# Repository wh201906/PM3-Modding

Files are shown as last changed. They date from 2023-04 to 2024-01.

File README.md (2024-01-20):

# PM3 Modding

## PM3_Flash
Add the external SPI flash to the PM3 Easy  
[README](/PM3_Flash/README.md)  
[Schematic](./PM3_Flash/hardware/PM3_Flash-schematic.pdf)  
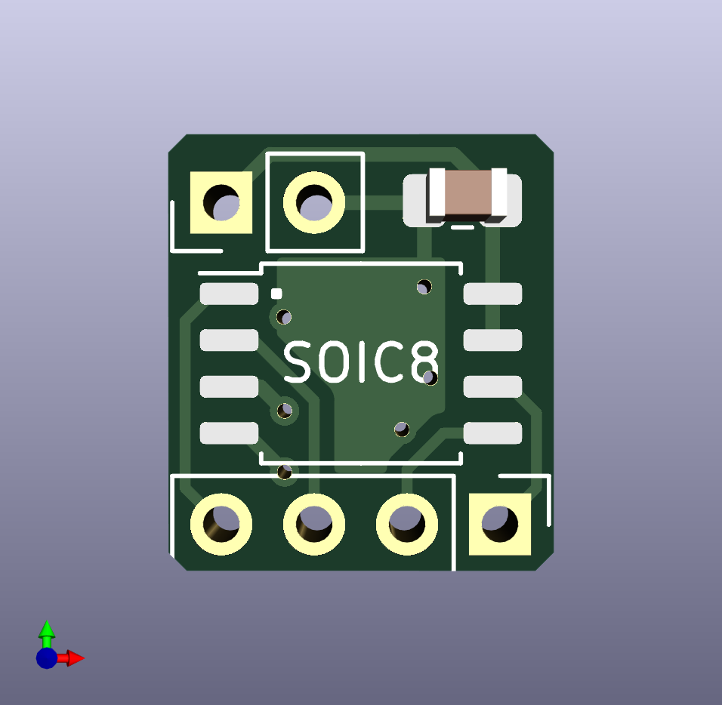
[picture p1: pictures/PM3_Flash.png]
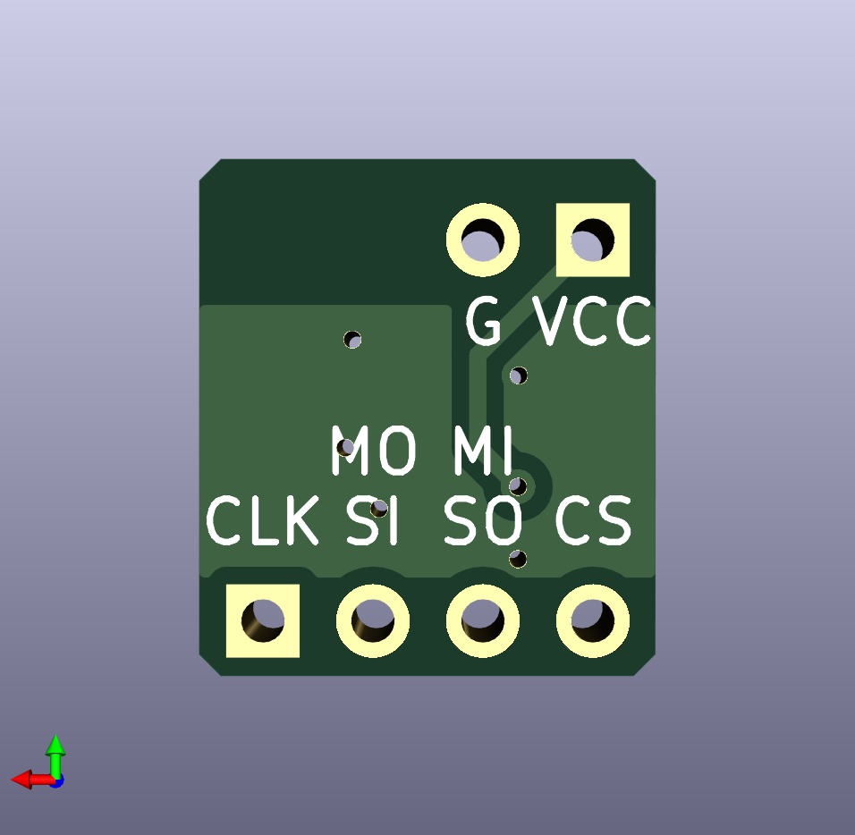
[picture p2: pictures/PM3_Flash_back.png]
    

## PM3_ISO7816
Add the smartcard module to the PM3 Easy  
[README](/PM3_ISO7816/README.md)  
[Schematic](./PM3_ISO7816/hardware/PM3_ISO7816-schematic.pdf)  
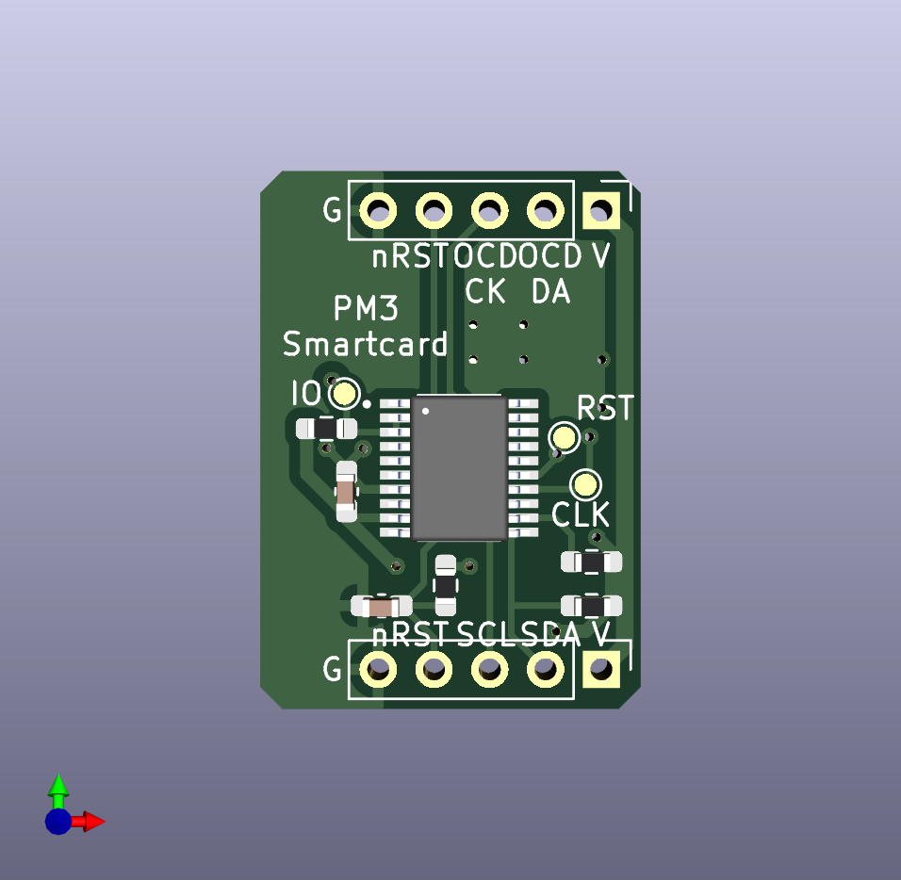
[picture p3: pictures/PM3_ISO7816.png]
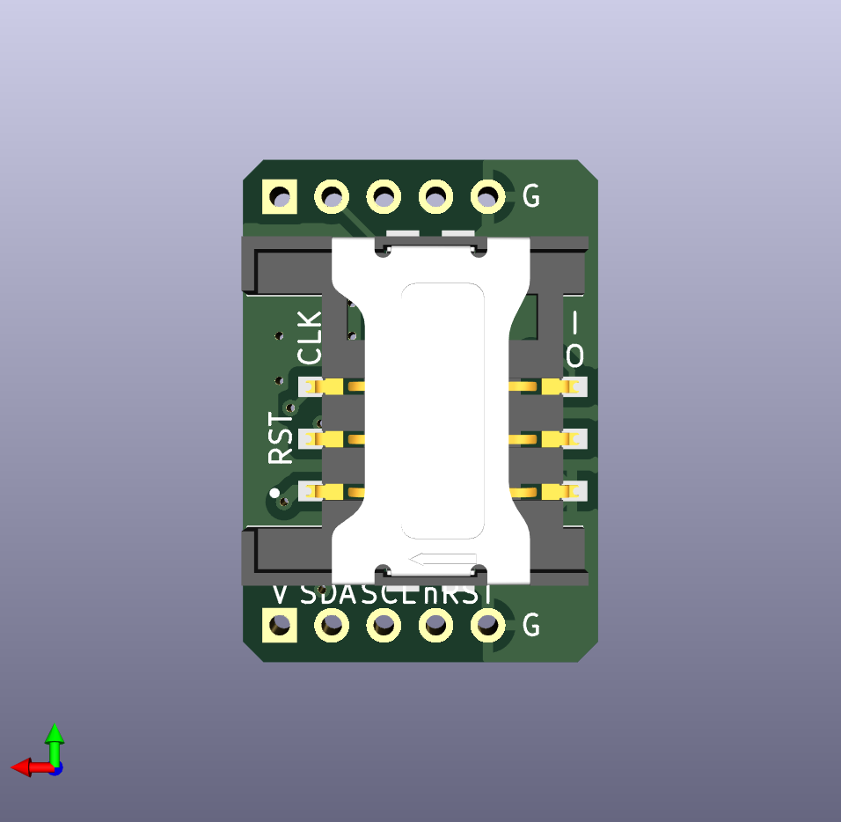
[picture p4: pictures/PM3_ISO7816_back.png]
    

## PM3_USB2TCP
[README](/PM3_USB2TCP/README.md)  
Connect to PM3 hardware with TCP, using ESP32-S3/S2 as a USB to TCP bridge  
No need to jumping any wires to the MCU directly. It works with most of the ESP32-S3/S2 dev boards  

## PM3_USB2UDP
[README](/PM3_USB2UDP/README.md)  
Connect to PM3 hardware with UDP, like `PM3_USB2TCP` but faster  

## License
All hardware projects in this repository are licensed under [CERN Open Hardware Licence Version 2 - Weakly Reciprocal](LICENSE.CERN-OHL-W).  
All software(firmware) projects in this repository are licensed under [GNU General Public License v3.0](LICENSE.GPL).

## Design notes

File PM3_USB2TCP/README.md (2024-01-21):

# PM3 USB to TCP Bridge

Connect to PM3 hardware with TCP, using ESP32-S3/S2 as a USB to TCP bridge.  
This modding only contains the firmware of ESP32-S3, and it should work on most of the ESP32-S3 and ESP32-S2 dev boards.  

# Tips:
1. To use this modding, you need a Proxmark3 client newer than commit [9c947eddcdbc66e76be6b33be9af4ce75e730b92](https://github.com/RfidResearchGroup/proxmark3/commit/9c947eddcdbc66e76be6b33be9af4ce75e730b92)
2. You need ESP-IDF or GitHub Action to build this project
3. The ESP32-S3 can work as a soft-AP. The SSID and the password are defined in [PM3_Modding/PM3_USB2TCP/firmware/main/wifi/wifi.h](./firmware/main/wifi/wifi.h)
4. To connect to an existing AP like wireless router or mobile hotspot, you should follow these steps:  
    + Set the correct SSID and password in [PM3_Modding/PM3_USB2TCP/firmware/main/wifi/wifi.h](./firmware/main/wifi/wifi.h)
    + Comment out `wifi_init_softap();` in [PM3_Modding/PM3_USB2TCP/firmware/main/app_main.c](./firmware/main/app_main.c)
    + Uncomment `wifi_init_sta();` in [PM3_Modding/PM3_USB2TCP/firmware/main/app_main.c](./firmware/main/app_main.c)
    + To get the IP address allocated by the DHCP server, you can check the output on UART0(GPIO43 for Tx, GPIO44 for Rx) or the management page of the router
    + (Optional) If it's not convenient to get the allocated IP address, you can set the static IP address in [PM3_Modding/PM3_USB2TCP/firmware/main/wifi/wifi.h](./firmware/main/wifi/wifi.h)
5. The default IP address of ESP32-S3 is `192.168.4.1`(soft-AP mode). The server port is defined in [PM3_Modding/PM3_USB2TCP/firmware/main/tcp-server.h](./firmware/main/tcp-server.h)
6. ESP32-S2 also has the USB-Host peripheral, so it also works. Remember to set the correct target chip in ESP-IDF.
7. Some of the arguments mentioned above can be configured by running `idf.py menuconfig` -> `USB Bridge Configuration`.

# Hardware Connection

| ESP32-S3 | PM3 |
| --- | --- |
| GND | GND |
| GPIO19 | USB_D- |
| GPIO20 | USB_D+ |
| 5V | 5V |

The 5V pin is optional.

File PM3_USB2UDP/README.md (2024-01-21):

# PM3 USB to UDP Bridge

Connect to PM3 hardware with UDP, using ESP32-S3/S2 as a USB to UDP bridge.  
This modding only contains the firmware of ESP32-S3, and it should work on most of the ESP32-S3 and ESP32-S2 dev boards.  

# Tips:
1. To use this modding, you need a Proxmark3 client newer than commit [0c0967bcc56773e0b014fd4d89d5f893052928d3](https://github.com/RfidResearchGroup/proxmark3/commit/0c0967bcc56773e0b014fd4d89d5f893052928d3)
2. You need ESP-IDF or GitHub Action to build this project
3. The ESP32-S3 can work as a soft-AP. The SSID and the password are defined in [PM3_Modding/PM3_USB2UDP/firmware/main/wifi/wifi.h](./firmware/main/wifi/wifi.h)
4. To connect to an existing AP like wireless router or mobile hotspot, you should follow these steps:  
    + Set the correct SSID and password in [PM3_Modding/PM3_USB2UDP/firmware/main/wifi/wifi.h](./firmware/main/wifi/wifi.h)
    + Comment out `wifi_init_softap();` in [PM3_Modding/PM3_USB2UDP/firmware/main/app_main.c](./firmware/main/app_main.c)
    + Uncomment `wifi_init_sta();` in [PM3_Modding/PM3_USB2UDP/firmware/main/app_main.c](./firmware/main/app_main.c)
    + To get the IP address allocated by the DHCP server, you can check the output on UART0(GPIO43 for Tx, GPIO44 for Rx) or the management page of the router
    + (Optional) If it's not convenient to get the allocated IP address, you can set the static IP address in [PM3_Modding/PM3_USB2UDP/firmware/main/wifi/wifi.h](./firmware/main/wifi/wifi.h)
5. The default IP address of ESP32-S3 is `192.168.4.1`(soft-AP mode). The server port is defined in [PM3_Modding/PM3_USB2UDP/firmware/main/tcp-server.h](./firmware/main/udp-server.h)
6. ESP32-S2 also has the USB-Host peripheral, so it also works. Remember to set the correct target chip in ESP-IDF.
7. Some of the arguments mentioned above can be configured by running `idf.py menuconfig` -> `USB Bridge Configuration`.

# Hardware Connection

| ESP32-S3 | PM3 |
| --- | --- |
| GND | GND |
| GPIO19 | USB_D- |
| GPIO20 | USB_D+ |
| 5V | 5V |

The 5V pin is optional.

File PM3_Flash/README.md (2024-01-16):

# PM3 Flash

Add the external SPI flash to the Proxmark3 Easy, to unlock all of the standalone modes.  

# Tips:
1. Some of the new Proxmark3 Easy has already intergrated an external SPI flash. If you know how to flash the firmware to the Proxmark3 Easy, you can try to flash a SPI flash enabled firmware to test if the external flash exists.
2. The SPI flash chip will be powered at 3.3V, but some SPI flash chips on the market can only be powered at 1.xV.
3. The SPI flash on the Proxmark3 RDV4 has a capacity of 256kBytes, but you can also use chips with higher capacity. Only 256kBytes will be used unless you changed the code of the firmware.
4. To use the SPI flash, you need to flash your Proxmark3 with SPI flash enabled firmware.
5. To initialize the SPI flash, you need to run the [Proxmark3/client/luascripts/init_rdv4.lua](https://github.com/RfidResearchGroup/proxmark3/blob/v4.16717/client/luascripts/init_rdv4.lua) in the client.

# Soldering

| Module | MCU  |
| --- | ---- |
| VCC | 3.3V |
| GND | GND  |
| CLK | PA14 |
| MISO | PA12 |
| MOSI | PA13 |
| CS | PA10 |

Please refer to the datasheet of AT91SAM7Sxxx to find the physical position of these pins.  
For some of the old Proxmark3 Easy, the PA14_SPCK, PA12_MISO and PA13_MOSI pin are exported near the JTAG pins. You only need to jump 1 wire(PA10_NPCS2) to the MCU directly.

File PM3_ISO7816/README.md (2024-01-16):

# PM3 ISO7816

Add the smartcard module to the Proxmark3 Easy.  

# Tips:
1. The MCU on the original smartcard module is Nuvoton's N76E003xQ20. I use the TSSOP-20 package(N76E003AT20) rather than QFN-20 package for easier manufacturing. The firmware works on both of them.
2. The firmware is separated into LDROM(kinda like bootloader) and APROM. To use this module, you need to flash the LDROM and APROM to the MCU first. 
3. The APROM can be found in the [Proxmark3 RRG repo](https://github.com/RfidResearchGroup/proxmark3/blob/v4.16717/client/resources/sim013.bin) with its [source code](https://github.com/RfidResearchGroup/proxmark3/blob/v4.16717/tools/simmodule/sim013.asm). The LDROM is [PM3_Modding/PM3_ISO7816/firmware/LDROM.bin](./firmware/LDROM.bin), which is closed-source and unreleased. I managed to get it from an original smartcard module.
4. You need to flash your Proxmark3 with smartcard module enabled firmware in order to use this module.

# Soldering

| Module | MCU  |
| --- | ---- |
| VCC | 3.3V |
| SDA | PA7  |
| SCL | PA5  |
| nRST | PA1  |
| GND | GND  |

Please refer to the datasheet of AT91SAM7Sxxx to find the physical position of these pins.  
For some of the old Proxmark3 Easy, the PA1 pin is exported near the JTAG pins. You only need to jump 2 wires(PA5, PA7) to the MCU directly.

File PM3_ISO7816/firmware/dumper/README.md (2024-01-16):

This project is based on `N76E003_BSP_Keil_C51_V1.0.6.zip` -> `Sample_Code\UART1_printf`, with these changes:  

+ Add common dependencies  
+ Remove some unused functions and macros  
+ Remove division  

To read the data in flash:  
(Including CONFIG bytes, LDROM and part of the APROM)  
1. copy the `dumper.bin` and `dumper.sha512.txt` into the `resource` folder of the client  
2. run `smart upgrade -f dumper.bin` in the client  
3. Connect the DAT pin of the smartcard module to the Rx pin of a USB to serial adapter
4. Open the corresponding serial port. (baudrate=115200, databits=8, stopbits=1)
5. run `hw status` in the client
6. Now you get the data from the serial port

The first 5 bytes are CONFIG0 ~ CONFIG4  
Then 1024 bytes of LDROM  
Then 17408 bytes of APROM(The first 384 bytes are overwritten by the dumper.bin)  
If your serial monitor supports splitting frames by timeout, just set the timeout to ~1350ms, then you will get the data above split into three frames.  

The `hex2bin.exe` is from https://sourceforge.net/projects/hex2bin/

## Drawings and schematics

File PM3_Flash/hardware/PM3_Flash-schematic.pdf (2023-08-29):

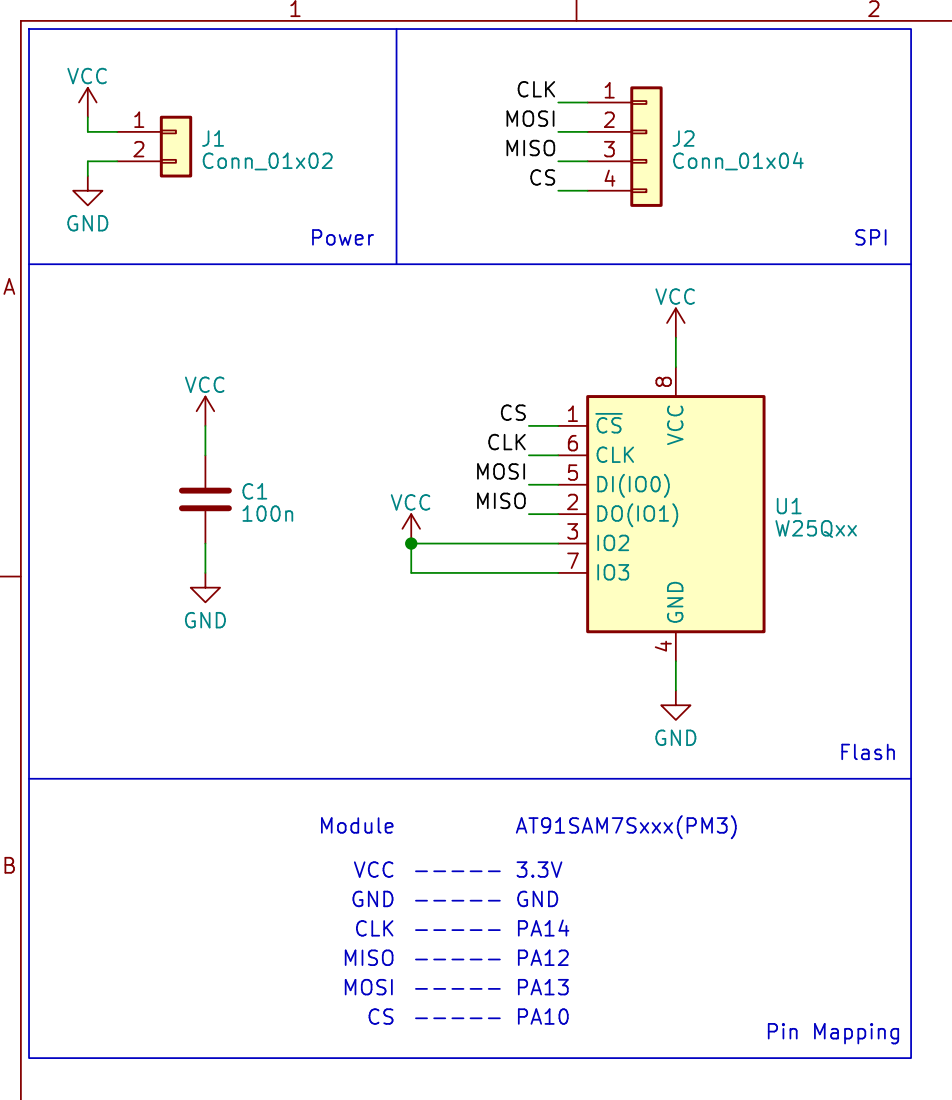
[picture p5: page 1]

CLKCS MOSI MOSI CLKCS CLKCS Module VCC
J1Conn_01x02 GND

Id: 1/1 Title: File: PM3_Flash.kicad_sch Sheet: /

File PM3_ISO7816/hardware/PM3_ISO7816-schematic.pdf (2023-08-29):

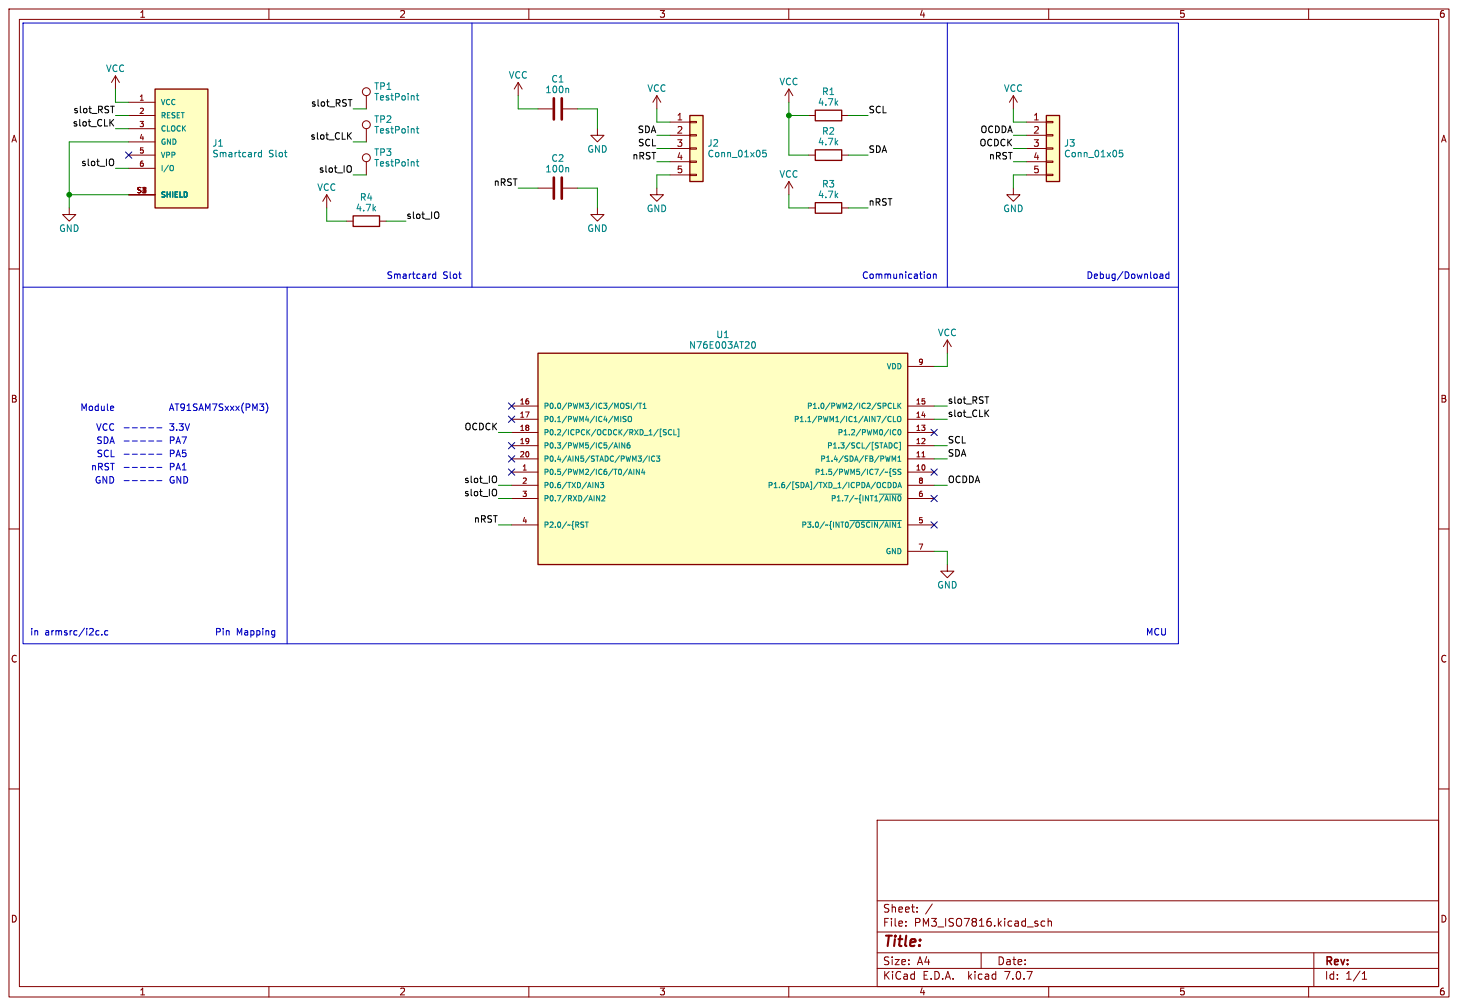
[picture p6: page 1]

Id: 1/1 Title: File: PM3_ISO7816.kicad_sch Sheet: /

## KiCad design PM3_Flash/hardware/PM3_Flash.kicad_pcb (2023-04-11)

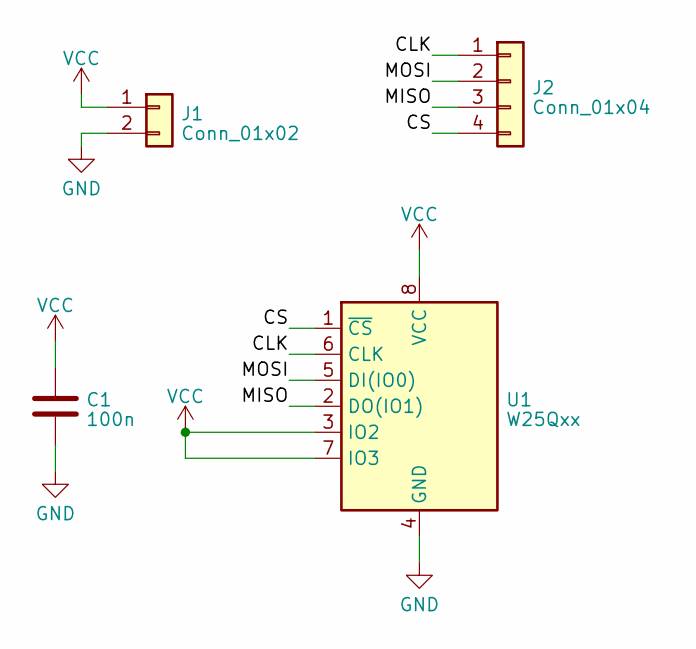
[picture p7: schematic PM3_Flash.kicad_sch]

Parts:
C1: 100n; C_0805_2012Metric_Pad1.18x1.45mm_HandSolder
J1: Conn_01x02; PinHeader_1x02_P2.54mm_Vertical
J2: Conn_01x04; PinHeader_1x04_P2.54mm_Vertical
U1: W25Qxx; SOIC-8_5.23x5.23mm_P1.27mm

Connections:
/CLK: J2.1, U1.6 (CLK)
/CS: J2.4, U1.1 (~CS)
/MISO: J2.3, U1.2 (DO(IO1))
/MOSI: J2.2, U1.5 (DI(IO0))
GND: C1.2, J1.2, U1.4 (GND)
VCC: C1.1, J1.1, U1.3 (IO2), U1.7 (IO3), U1.8 (VCC)

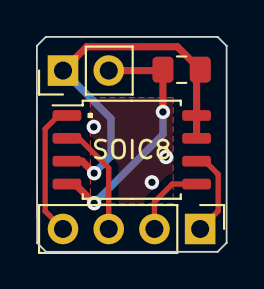
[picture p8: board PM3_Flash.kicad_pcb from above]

Board: 2 copper layers, 10.5 x 11.9 mm, 4 parts (0 on the bottom side), 6 nets.

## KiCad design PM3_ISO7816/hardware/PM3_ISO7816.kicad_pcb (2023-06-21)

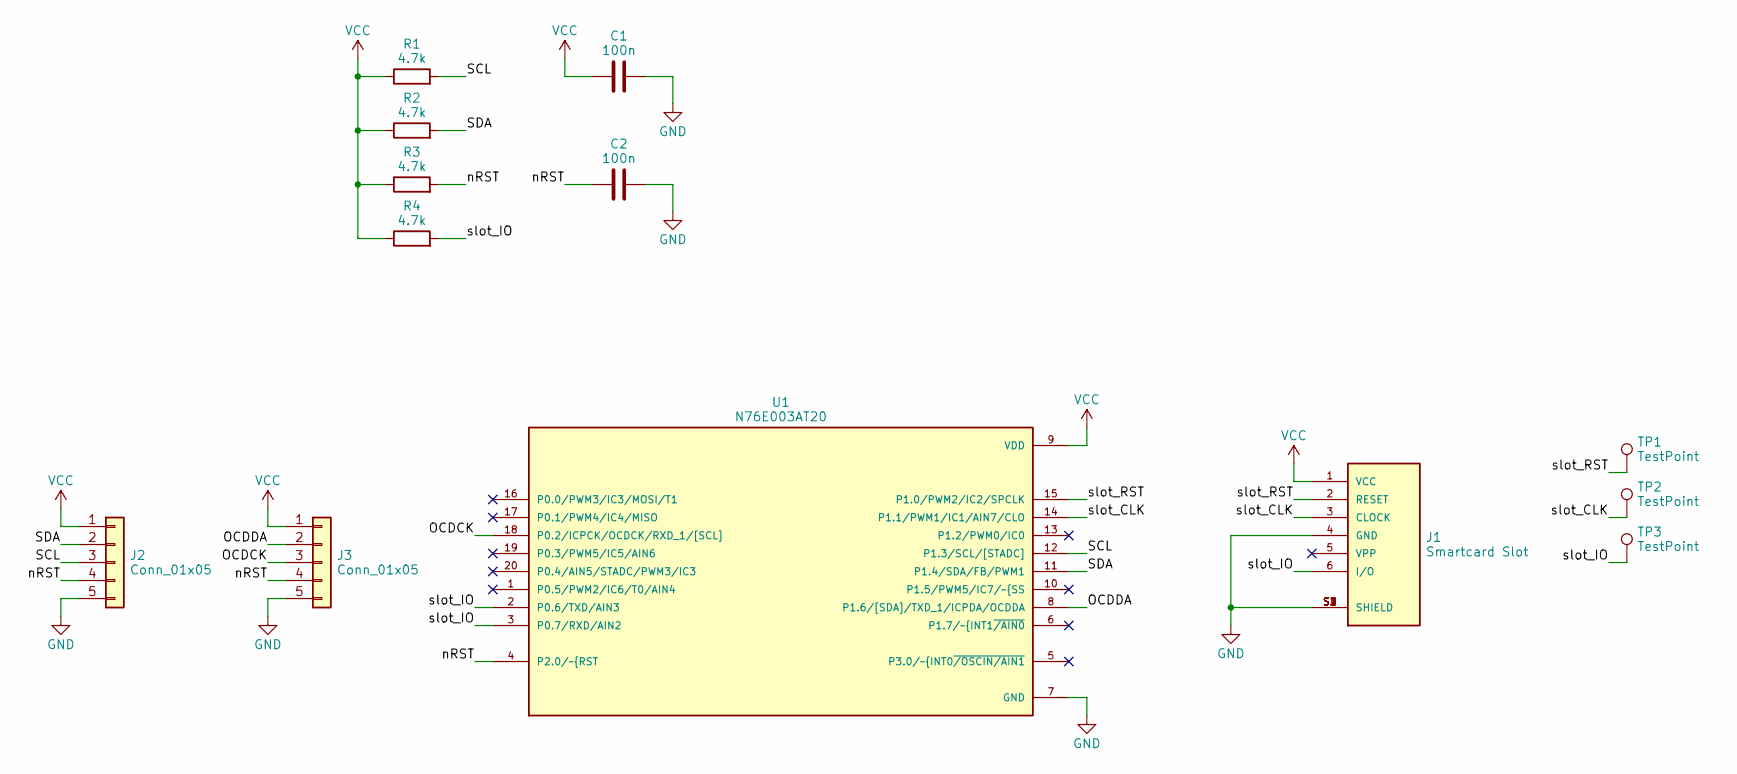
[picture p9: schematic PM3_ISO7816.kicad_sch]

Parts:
C1, C2: 100n; C_0603_1608Metric_Pad1.08x0.95mm_HandSolder
J1: Smartcard Slot; WURTH_693010020611; PARTREV F
J2, J3: Conn_01x05; PinHeader_1x05_P2.54mm_Vertical
R1, R2, R3, R4: 4.7k; R_0603_1608Metric_Pad0.98x0.95mm_HandSolder
TP1, TP2, TP3: TestPoint; TestPoint_Pad_D1.0mm
U1: N76E003AT20; SOP65P640X120-20N; PARTREV 1.04

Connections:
/OCDCK: J3.3, U1.18 (P0.2/ICPCK/OCDCK/RXD_1/[SCL])
/OCDDA: J3.2, U1.8 (P1.6/[SDA]/TXD_1/ICPDA/OCDDA)
/SCL: J2.3, R1.2, U1.12 (P1.3/SCL/[STADC])
/SDA: J2.2, R2.2, U1.11 (P1.4/SDA/FB/PWM1)
/nRST: C2.1, J2.4, J3.4, R3.2, U1.4 (P2.0/~RST~{)
/slot_CLK: J1.3 (CLOCK), TP2.1, U1.14 (P1.1/PWM1/IC1/AIN7/CLO)
/slot_IO: J1.6 (I/O), R4.2, TP3.1, U1.2 (P0.6/TXD/AIN3), U1.3 (P0.7/RXD/AIN2)
/slot_RST: J1.2 (RESET), TP1.1, U1.15 (P1.0/PWM2/IC2/SPCLK)
GND: C1.2, C2.2, J1.4 (GND), J1.S1 (SHIELD), J1.S2 (SHIELD), J1.S3 (SHIELD), J1.S4 (SHIELD), J2.5, J3.5, U1.7 (GND)
VCC: C1.1, J1.1 (VCC), J2.1, J3.1, R1.1, R2.1, R3.1, R4.1, U1.9 (VDD)

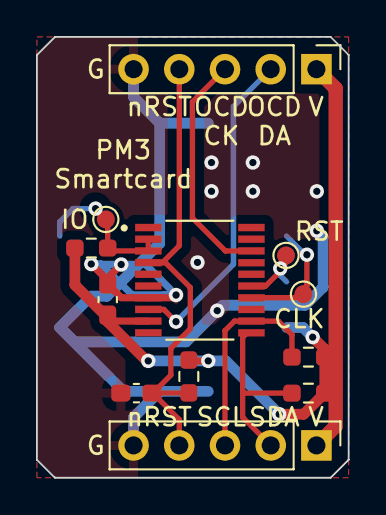
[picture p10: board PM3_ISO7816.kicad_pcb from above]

Board: 2 copper layers, 17.3 x 24.5 mm, 13 parts (1 on the bottom side), 10 nets.

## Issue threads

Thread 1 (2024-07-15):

Unable to Connect Proxmark3 via ESP32-S2 USB to UDP Bridge

sleepwalkera, 2024-07-15:
Hello,

I have been testing the ESP32-S2 firmware for the USB to UDP bridge functionality for Proxmark3 as described in this repository. Despite following the instructions, I am unable to establish a connection between the Proxmark3 client and the Proxmark3 device. Here are the steps I followed and the issues I encountered:

1. I successfully connected to the Wi-Fi hotspot created by the ESP32-S2 and was able to ping 192.168.4.1. An nmap scan confirmed that the UDP port 18888 on 192.168.4.1 is open.
2. However, when I attempt to connect to the Proxmark3 using the command `pm3 -p udp:192.168.4.1:18888`, the connection fails. The log output is as follows:

```
pm3 -p udp:192.168.4.1:18888
[=] Session log xxx.txt
[+] loaded `xxx/preferences.json`
[+] Using UART port udp:192.168.4.1:18888
[!!] 🚨 ERROR: cannot communicate with the Proxmark3
```

3. Both the client and device are running Proxmark3 firmware version v4.18589 - Aurora.

I would appreciate any guidance or suggestions to troubleshoot and resolve this issue. Thank you in advance for your help!

wh201906, 2024-07-15:
Have you tried the TCP version?

sleepwalkera, 2024-07-16:
I tested the TCP version, but had no luck. It appears that port 18888 is closed.

`$ nmap 192.168.4.1 -p 18888
Starting Nmap 7.70 ( https://nmap.org ) at 2024-07-16 16:06 CST
Nmap scan report for 192.168.4.1
Host is up (0.018s latency).

PORT      STATE  SERVICE
18888/tcp closed apc-necmp

Nmap done: 1 IP address (1 host up) scanned in 13.08 seconds`

wh201906, 2024-07-20:
I don't have a valid ESP32-S2 now so I cannot test it.

> It appears that port 18888 is closed.

This is unexpected. Did you connect the Proxmark3 hardware to the ESP32-S2?

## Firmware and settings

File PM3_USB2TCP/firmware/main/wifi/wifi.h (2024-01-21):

#pragma once

#include "esp_wifi.h"
#include "sdkconfig.h"

#if !CONFIG_BRIDGE_USE_CONFIG 
    // Items in Kconfig are not used unless configured

    // For AP/Station
    #define WIFI_SSID    "PM3_ESPBridge"
    #define WIFI_PWD     "[PM3_USB]"

    // For station only
    // If WIFI_STA_STATIC_IP_ADDR is set to "", use allocated IP address.
    // Don't forget to set WIFI_STA_STATIC_GATEWAY_ADDR if WIFI_STA_STATIC_IP_ADDR is specified.
    #define WIFI_STA_STATIC_IP_ADDR         ""
    #define WIFI_STA_STATIC_NETMASK_ADDR    "255.255.255.0"
    #define WIFI_STA_STATIC_GATEWAY_ADDR    ""
    // DNS is unnecessary because it doesn't access the Internet
#else
    // Ignore this block if items in Kconfig are not used
    #define WIFI_SSID    CONFIG_BRIDGE_WIFI_SSID
    #define WIFI_PWD     CONFIG_BRIDGE_WIFI_PASSWORD
    #if !CONFIG_BRIDGE_WIFI_STA_USE_STATIC_IP
        #define WIFI_STA_STATIC_IP_ADDR         ""
        #define WIFI_STA_STATIC_NETMASK_ADDR    "255.255.255.0"
        #define WIFI_STA_STATIC_GATEWAY_ADDR    ""
    #else
        #define WIFI_STA_STATIC_IP_ADDR         CONFIG_BRIDGE_WIFI_STA_STATIC_IP_ADDR
        #define WIFI_STA_STATIC_NETMASK_ADDR    CONFIG_BRIDGE_WIFI_STA_STATIC_NETMASK_ADDR
        #define WIFI_STA_STATIC_GATEWAY_ADDR    CONFIG_BRIDGE_WIFI_STA_STATIC_GATEWAY_ADDR
    #endif
#endif

// For AP only
#define WIFI_AP_CHANNEL 5
#define WIFI_AP_MAX_STA_CONN 3

// For station only
#define WIFI_STA_MAX_RETRY 3
#define WIFI_STA_H2E_IDENTIFIER ""

static const char *TAG_WIFI = "Wifi";

void wifi_init_softap(void);
void wifi_init_sta(void);

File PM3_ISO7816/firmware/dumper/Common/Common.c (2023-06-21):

/*---------------------------------------------------------------------------------------------------------*/
/*                                                                                                         */
/* Copyright(c) 2016 Nuvoton Technology Corp. All rights reserved.                                         */
/*                                                                                                         */
/*---------------------------------------------------------------------------------------------------------*/

//***********************************************************************************************************
//  Nuvoton Technoledge Corp.
//  Website: http://www.nuvoton.com
//  E-Mail : MicroC-8bit@nuvoton.com
//  Date   : Apr/21/2016
//***********************************************************************************************************

#include "N76E003.h"
#include "Common.h"
#include "Delay.h"
#include "SFR_Macro.h"
#include "Function_define.h"

//----------------------------------------------------------------------------------
// UART1 baud rate initial setting
//----------------------------------------------------------------------------------
void InitialUART1_Timer3() //use timer3 as Baudrate generator
{
  P02_Quasi_Mode; //Setting UART pin as Quasi mode for transmit
  P16_Quasi_Mode; //Setting UART pin as Quasi mode for transmit

  SCON_1 = 0x50; //UART1 Mode1,REN_1=1,TI_1=1
  T3CON = 0x08;  //T3PS2=0,T3PS1=0,T3PS0=0(Prescale=1), UART1 in MODE 1
  clr_BRCK;

#ifdef FOSC_160000
  RH3 = HIBYTE(65536 - (1000000 / (UINT32)BAUDRATE) - 1); /*16 MHz */
  RL3 = LOBYTE(65536 - (1000000 / (UINT32)BAUDRATE) - 1); /*16 MHz */
#endif
#ifdef FOSC_166000
  RH3 = HIBYTE(65536 - (1037500 / (UINT32)BAUDRATE); /*16.6 MHz */
  RL3 = LOBYTE(65536 - (1037500 / (UINT32)BAUDRATE); /*16.6 MHz */
#endif
  set_TR3; //Trigger Timer3
}

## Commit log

2023-04-02 First version
    [PM3_Flash.kicad_pcb, PM3_Flash.kicad_sch]
2023-04-02 pcb: better layout
    [PM3_Flash.kicad_pcb]
2023-04-03 pcb: gerber output config for JLCPCB
    [PM3_Flash.kicad_pcb]
2023-04-04 pcb: optimize filled zone
    [PM3_Flash.kicad_pcb]
2023-06-16 Add project for Smartcard slot
    [PM3_Flash.kicad_pcb, PM3_Flash.kicad_sch, PM3_ISO7816.kicad_pcb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]
2023-06-21 Smartcard: Add firmware and firmware dumper
    [PM3_ISO7816.kicad_pcb, PM3_ISO7816.kicad_sch]
2023-06-21 Smartcard: Misc work on PCB
    Swap VCC pin and GND pin to match the pin order of Nu-Link
    Change the footprint of sim card slot for hand soldering
    Add test points
    [PM3_ISO7816.kicad_pcb, PM3_ISO7816.kicad_sch]
2023-07-04 USB2TCP: Open Proxmark3
    Set VID&PID for Proxmark3
    Use cdc_acm_host_open_vendor_specific()
    Remove unused code
2023-07-05 USB2TCP: Demo
    Based on:
    esp-idf-v5.0.2\examples\protocols\sockets\non_blocking
    esp-idf-v5.0.2\examples\peripherals\usb\host\cdc\cdc_acm_host
    esp-idf-v5.0.2\examples\wifi\getting_started\softAP
2023-07-06 Misc
    Move PM3_Flash hardware project to PM3_Flash/hardware/
    Add LICENSE
    Add README.md
    [PM3_Flash.kicad_pcb, PM3_Flash.kicad_sch]
2023-08-29 Add schematic pdf
    [PM3_Flash.kicad_sch, PM3_ISO7816.kicad_sch]
2023-08-29 Fix an error in README
    Bluetooth Classic is supported on ESP32-S3
    https://docs.espressif.com/projects/esp-idf/zh_CN/latest/esp32s3/api-reference/bluetooth/index.html
2024-01-19 USB2UDP: Speed up
    Use usb_host_cdc_acm 2.x with configurable in_buffer_size
    Increase buffer size
    Replace ESP_LOGI() with printf() in RX/TX functions for less overhead
    Now the communication speed is higher than 200kByte/s, but this app
    still cannot support the real-time sampling due to the response time of
    packets.
2024-01-20 USB2UDP: Fix some bugs
    Remove duplicate calls to esp_netif_init()
    Fix a deleted line
    Keep UDP socket alive if the errno is EAGAIN
2024-01-20 USB2TCP: Apply changes from USB2UDP
    From:
    commit 802f700ba82fae288bfdcc3b76f7ac163e3ee7fd
    commit da60cc311849981c28d874ea1f5d1336404f0a1f
    commit cb4072ead64cac6db27412ef75d6a978f8586e7b
    commit b806c8f10350a6b2b6db0749399d6da61b53b231
    `lf sniff` and `hw status` doesn't work in the Wifi station mode.
    IDK if it's caused by the app or the client.
    [wifi.h]
